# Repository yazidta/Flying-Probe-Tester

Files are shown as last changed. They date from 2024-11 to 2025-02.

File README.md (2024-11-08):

Flying Probe Tester for Single-Layer PCBs

This project is a Flying Probe Tester designed to perform connectivity testing on single-layer PCBs. 
The system uses two probes to make precise measurements across various points on the PCB,
identifying short circuits, open circuits, and verifying component placements and connections.

Key Features
Two-Probe System: Includes two probes for flexible testing of connections on single-layer PCBs.
Single-Layer PCB Support: Optimized for single-layer boards, providing efficient testing of simpler PCBs.
Automated Testing Sequences: Capable of performing automated testing sequences, saving time and improving accuracy.
Easy Setup and Calibration: Straightforward configuration for fast setup and reliable testing.
How It Works
The flying probe tester positions the probes over test points on the PCB and applies electrical signals to verify connections. 
This approach allows for rapid identification of faults without the need for dedicated test fixtures, making it suitable for both prototyping and small production runs.

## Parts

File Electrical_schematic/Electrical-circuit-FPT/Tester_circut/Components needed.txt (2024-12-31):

- 1x Buzzer with generator: (https://botland.com.pl/buzzery-generatory-dzwieku/786-buzzer-z-generatorem-5v-12mm-tht-5904422366940.html)
- 2x Resistor 100 ohm
- 1x Transistor BC547: (https://botland.com.pl/tranzystory-npn/254-tranzystor-bipolarny-npn-bc547b-50v-01a-5szt-5904422308025.html)

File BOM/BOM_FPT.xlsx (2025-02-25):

Component | Quantity | Price | Price x Quantity
Ball bearing 608 2RS 8x22x7mm 1 Set(10pcs) | 2 | PLN 9.50 | PLN 19.00
Round rod 56 cm x 12 mm 2 pcs. | 5 | PLN 23.95 | PLN 119.75
Linear Bearing | 8 | PLN 5.95 | PLN 47.60
Servo SG90 | 2 | PLN 12.70 | PLN 25.40
Toothed belt GT2 6mm 2m black | 2 | PLN 13.20 | PLN 26.40
FLEXIBLE ALUMINUM CLUTCH 5x8mm | 2 | PLN 6.39 | PLN 12.78
Bigtreetech TMC2209 v1.3 Stepper Motor Driver | 4 | PLN 27.90 | PLN 111.60
Mini limit switch sensor - WK601 - 5 pcs. | 1 | PLN 3.19 | PLN 3.19
Stepper motor JK42HS40-0504 200 steps/rev 12V/0.5A/0.43Nm | 2 | PLN 69.00 | PLN 138.00
140 jumper wires for breadboards | 1 | PLN 9.90 | PLN 9.90
Roll 625ZZ V-slot Ender 3 3D Printer 4 pcs | 2 | PLN 18.99 | PLN 37.98
Encoder with button | 1 | PLN 13.90 | PLN 13.90
4x20 LCD screen | 1 | PLN 34.90 | PLN 34.90
micro SD card | 1 | PLN 15.93 | PLN 15.93
Micro SD card reader | 1 | PLN 4.60 | PLN 4.60
NPN Transistors | 1 | PLN 1.90 | PLN 1.90
100 Ohm resistors | 1 | PLN 1.90 | PLN 1.90
Female - male cables | 2 | PLN 6.50 | PLN 13.00
Male to Male cables | 2 | PLN 6.50 | PLN 13.00
Female - female cables | 1 | PLN 6.50 | PLN 6.50
Buttons | 1 | PLN 3.90 | PLN 3.90
Power supply | 1 | PLN 44.90 | PLN 44.90
STM board | 1 | PLN 139.00 | PLN 139.00
Breadboard | 1 | PLN 7.70 | PLN 7.70
Capacitor 1uF 10pcs | 1 | PLN 1.50 | PLN 1.50
Converter | 3 | PLN 9.90 | PLN 29.70
Printed board | 1 | PLN 7.50 | PLN 7.50
On-Off switch | 1 | PLN 2.90 | PLN 2.90
Stepper motor LDO-42STH25-1404MAC | 2 | PLN 65.01 | PLN 130.02
Trapezoidal screws | 2 | PLN 26.99 | PLN 53.98
 |  | Total | PLN 1078.33

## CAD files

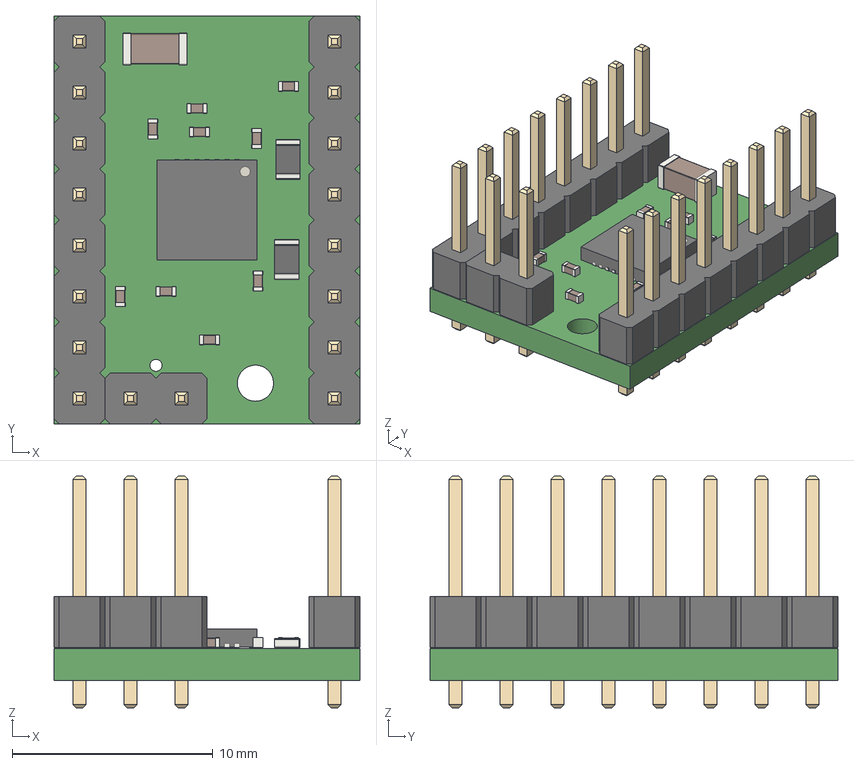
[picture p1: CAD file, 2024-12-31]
Electrical_schematic/Electrical-circuit-FPT/SilentStepStickKiCad-master/SilentStepStickKiCad-master/SilentStepStick-TMC2209_v20.step
15.2 x 20.3 x 11.5 mm

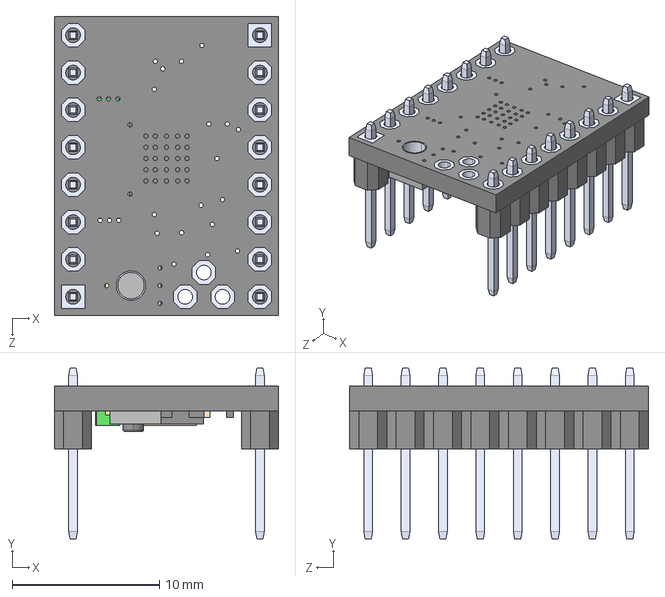
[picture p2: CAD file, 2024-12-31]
Electrical_schematic/Electrical-circuit-FPT/TMC2209_SILENTSTEPSTICK/TMC2209_SILENTSTEPSTICK.step
15.2 x 11.6 x 20.3 mm

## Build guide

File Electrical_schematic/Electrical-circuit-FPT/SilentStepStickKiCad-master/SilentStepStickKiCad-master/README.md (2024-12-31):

# SilentStepStickKiCad
SilentStepStick TMC2209 imported to KiCad

Imported https://github.com/watterott/SilentStepStick into KiCad.
Added 3D Models from KiCads Library.

Attribution goes to https://github.com/watterott.

Open-Source and released under the Creative Commons Attribution Share-Alike License.
https://creativecommons.org/licenses/by-sa/4.0/

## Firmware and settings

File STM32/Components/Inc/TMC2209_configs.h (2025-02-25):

/******************************************************************************
 * @file       TMC2209.cpp
 * @author     Ahmed Bouras
 * @date       05/12/2024
 * @version    0.6
 *
 * @copyright  Copyright (c) [2024] Ahmed Bouras
 *
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
 * @note       This library provides an interface for controlling the TMC2209
 *             stepper motor driver over STEP, DIR, ENN & UART.
 ******************************************************************************
 */
#ifndef TMC2209_CONFIGS_H
#define TMC2209_CONFIGS_H

#include "stm32f7xx_hal.h"
#include "stdbool.h"



// Timer Handler declaration for motors
extern TIM_HandleTypeDef htim1;
extern TIM_HandleTypeDef htim2;
extern TIM_HandleTypeDef htim3;
extern TIM_HandleTypeDef htim5;

// Motors & axis
#define MAX_MOTORS 4 // Max motors to be added -- You can handle upto 4 TMC2209 drivers on the same UART BUS
#define MAX_MOTORS_PER_AXIS 2 // Num of motors per axis
#define X_AXIS_LENGTH	469.356
#define Y_AXIS_LENGTH 	300


// DEFAULT DRIVERS CONFIGURATIONS

#define DEFAULT_MSTEP		16
#define DEFAULT_CHOPPERMODE	0
#define DEFAULT_SENDDELAY 	16
#define DEFAULT_IRUN 		12
#define DEFAULT_IHOLD 		6
#define DEFAULT_IDELAY		4
#define DEFAULT_COOLTHRS	5000
#define DEFAULT_SGTHRS		126
// DEFAULT MOTOR SPEED

#define DEFAULT_X_SPEED	8000
#define DEFAULT_Y_SPEED	8000







// Driver structure
typedef struct {
	uint8_t id;                      // Motor ID to identify each motor -- this is useless now ince we have address for uart
					//	Microstepping setting of the driver
    UART_HandleTypeDef *huart;
    uint8_t address;                // UART address
    uint32_t STATUS;
    TIM_HandleTypeDef *htim;        // Timer handle for PWM generation
    uint32_t step_channel;          // PWM channel
    uint32_t stepFrequency; 		// speed

    // Motor Configurations
    uint16_t mstep;	     // Microstepping: 2,8,16,256, or FULLSTEP
    uint8_t chopperMode; // 1 for StealthChop, 0 for SpreadCycle. Default: 1
    uint8_t sendDelay;
    uint32_t IFCNT; // Sucessful write incrementing counter(This value gets incremented with every sucessful UART write access 0 to 255 then wraps around.)
    uint8_t pdn_disable; // PDN_DISABLE FOR UART
    uint8_t GCONF;
    uint8_t IRUN;
    uint8_t IHOLD;
    uint8_t IDELAY;
    uint8_t stallEnabled; // STALL enabled flag, this means that we will be able to read sg_result
    uint32_t SG_RESULT;
    uint8_t checkSG_RESULT; // flag to check sg_result
    int32_t TCoolThrs;  // TCoolThrs for Stall detection on DIAG pin(we will have to set the step frequency which stall will be triggered)
    uint8_t standstill; // this indict that the motor is in standstill from DRV_STATUS


    // GPIO PINS
    GPIO_TypeDef *step_port;
    uint16_t step_pin;
    GPIO_TypeDef *dir_port;
    uint16_t dir_pin;
    GPIO_TypeDef *enn_port;
    uint16_t enn_pin;
    GPIO_TypeDef *diag_port;
    uint16_t diag_pin;
    GPIO_TypeDef *index_port;
    uint16_t index_pin;




} TMC2209_Driver;

// Motor tracking

typedef struct {
    TMC2209_Driver driver;         // Driver settings for the motor
    uint32_t stepsPerRevolution;	// Steps per revolution of the motor
    uint32_t totalStepsPerRevolution; // we will calculate this later based on the mstep option the driver has
    uint8_t moveRequest; 		// Move request Flag -- USED FOR RTOS
    int32_t stepsTaken;           // Count of steps taken
    int32_t fullSteps;
    uint32_t nextTotalSteps;           // Total steps the motor should take
    uint32_t direction;				// Direction of the Motor
    float prevPositionMM;	// Previous position on the axis in millimeter to no start the motor if it's in already in the requested position.
    float currentPositionMM; // Current position on the axis in millimeters
    float nextPositionMM;
    double stepError;
    bool isStepping;               // State to track if the motor is currently stepping
    uint32_t StepsFront;           // Tracking Steps Based on direction
    int32_t StepsBack;
    float calib[2];
    uint8_t STALL;
} Motor;

// Axis structure
typedef struct {
    Motor *motors[MAX_MOTORS_PER_AXIS];           // Pointing to which motors controlling this axis
    float lengthMM;         // Total length of the axis in millimeters
    uint32_t totalSteps;    // Total steps the motor takes to cover the axis length -- You can get this value using limit switches
    float stepPerUnit;      // How much one step would move on the axis
    char id[MAX_MOTORS_PER_AXIS][10];          //  Axis name with Motor ID (e.g., "X1", Y1", "Z1") "1" stands for the motor ID which control the axis
} Axis;




extern Motor motors[MAX_MOTORS]; // Global motor array
extern Axis axes[MAX_MOTORS_PER_AXIS];


// Function declarations
void initializeMotors();
void initializeAxis(Axis *axis, Motor *motor1, Motor *motor2, uint8_t circumference, const char *axisName);
void initializeSystem();
void TMC2209_setMotorsConfiguration(Motor *motors);



#endif // TMC2209_CONFIGS_H

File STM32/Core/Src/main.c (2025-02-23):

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
/* Includes ------------------------------------------------------------------*/
#include "main.h"
#include "cmsis_os.h"
#include "fatfs.h"

/* USER CODE BEGIN Includes */

#include "lcd_config.h"
#include "encoder.h"
#include "encoder_config.h"
#include "stm32f7xx_hal.h"
#include "TMC2209.h"
#include "TMC2209_configs.h"
#include "servo.h"
#include "fatfs.h"
#include "calibration.h"
#include "app_tasks.h"

/* USER CODE END Includes */


I2C_HandleTypeDef hi2c1;

SPI_HandleTypeDef hspi2;

TIM_HandleTypeDef htim1;
TIM_HandleTypeDef htim2;
TIM_HandleTypeDef htim3;
TIM_HandleTypeDef htim4;
TIM_HandleTypeDef htim5;
TIM_HandleTypeDef htim7;
TIM_HandleTypeDef htim9;
TIM_HandleTypeDef htim14;

UART_HandleTypeDef huart4;
UART_HandleTypeDef huart5;
UART_HandleTypeDef huart2;
UART_HandleTypeDef huart3;
UART_HandleTypeDef huart6;
DMA_HandleTypeDef hdma_uart4_rx;
DMA_HandleTypeDef hdma_uart5_rx;
DMA_HandleTypeDef hdma_usart2_rx;
DMA_HandleTypeDef hdma_usart3_rx;
DMA_HandleTypeDef hdma_usart3_tx;
DMA_HandleTypeDef hdma_usart6_rx;

PCD_HandleTypeDef hpcd_USB_OTG_FS;

osThreadId defaultTaskHandle;
/* USER CODE BEGIN PV */


SERVO_Handle_TypeDef hservo1 = { .PwmOut = PWM_INIT_HANDLE(&htim14, TIM_CHANNEL_1), .ID= 1 };
SERVO_Handle_TypeDef hservo2 = { .PwmOut = PWM_INIT_HANDLE(&htim9, TIM_CHANNEL_1), .ID=2 };

Motor motors[MAX_MOTORS]; // Global motor array
Axis axes[MAX_MOTORS_PER_AXIS]; // Global axes array

volatile uint8_t flagUserBtn = 0;

// ENDTOP FLAGS:
volatile uint8_t ES1 = 0;
volatile uint8_t ES2 = 0;
volatile uint8_t ES3 = 0;
volatile uint8_t ES4 =0;

volatile uint8_t Btn1 = 0;
volatile uint8_t Btn2 = 0;
volatile uint8_t Btn3 = 0;
volatile uint8_t Btn4 =0;
volatile uint8_t Btn5 =0;

// Homing Flags

volatile uint8_t homingFlag = 0;
volatile uint8_t calibrationFlag =0;


void SystemClock_Config(void);
static void MX_GPIO_Init(void);
static void MX_DMA_Init(void);
static void MX_USART3_UART_Init(void);
static void MX_USB_OTG_FS_PCD_Init(void);
static void MX_TIM7_Init(void);
static void MX_TIM4_Init(void);
static void MX_TIM2_Init(void);
static void MX_USART2_UART_Init(void);
static void MX_SPI2_Init(void);
static void MX_TIM3_Init(void);
static void MX_TIM14_Init(void);
static void MX_TIM5_Init(void);
static void MX_TIM9_Init(void);
static void MX_I2C1_Init(void);
static void MX_USART6_UART_Init(void);
static void MX_UART4_Init(void);
static void MX_UART5_Init(void);
static void MX_TIM1_Init(void);
void StartDefaultTask(void const * argument);

/* USER CODE BEGIN 0 */

void HAL_GPIO_EXTI_Callback(uint16_t GPIO_Pin)
{
    if (GPIO_Pin == USER_Btn_Pin) // Check if the interrupt is for the correct button
    {

    flagUserBtn = 1;
    }

}
/* USER CODE END 0 */

/**
  * @brief  The application entry point.
  * @retval int
  */
int main(void)
{

  /* MCU Configuration--------------------------------------------------------*/

  /* Reset of all peripherals, Initializes the Flash interface and the Systick. */
  HAL_Init();

  /* Configure the system clock */
  SystemClock_Config();

  /* Initialize all configured peripherals */
  MX_GPIO_Init();
  MX_DMA_Init();
  MX_USART3_UART_Init();
  MX_USB_OTG_FS_PCD_Init();
  MX_TIM7_Init();
  MX_TIM4_Init();
  MX_TIM2_Init();
  MX_USART2_UART_Init();
  MX_FATFS_Init();
  MX_SPI2_Init();
  MX_TIM3_Init();
  MX_TIM14_Init();
  MX_TIM5_Init();
  MX_TIM9_Init();
  MX_I2C1_Init();
  MX_USART6_UART_Init();
  MX_UART4_Init();
  MX_UART5_Init();
  MX_TIM1_Init();
  /* USER CODE BEGIN 2 */

  LCD_I2C_Init(&hlcd3);
 // LCD_I2C_Clear(&hlcd3);

  SERVO_Init(&hservo1);
  SERVO_Init(&hservo2);

  ENC_Init(&henc1);


  //initializeSystem();




 // TMC2209_SetSpeed(&motors[0], 7000);
 // TMC2209_Start(&motors[0]);


  /* USER CODE END 2 */

  /* USER CODE BEGIN RTOS_MUTEX */
  /* add mutexes, ... */

  testingEvent = xEventGroupCreate();
  configASSERT(testingEvent != NULL);
  calibEventGroup = xEventGroupCreate();
  configASSERT(calibEventGroup != NULL);

  lcdMutex = xSemaphoreCreateMutex();
  /* USER CODE END RTOS_MUTEX */

  /* USER CODE BEGIN RTOS_SEMAPHORES */
  /* add semaphores, ... */
  xInitSemaphore = xSemaphoreCreateMutex();

  /* USER CODE END RTOS_SEMAPHORES */

  /* USER CODE BEGIN RTOS_TIMERS */
  /* start timers, add new ones, ... */
  /* USER CODE END RTOS_TIMERS */

  /* USER CODE BEGIN RTOS_QUEUES */
  /* add queues, ... */
  /* USER CODE END RTOS_QUEUES */

  /* Create the thread(s) */
  /* definition and creation of defaultTask */
//  osThreadDef(defaultTask, StartDefaultTask, osPriorityNormal, 0, 512);
//  defaultTaskHandle = osThreadCreate(osThread(defaultTask), NULL);

  /* USER CODE BEGIN RTOS_THREADS */
  /* add threads, ... */

//  const osThreadAttr_t motorTask_attributes = {
//		  .name = "motorControlTask",
//		  .priority = (osPriority_t) osPriorityNormal,
//		  .stack_size = 512  // TODO: Adjust the stack size?
//  };
//  osThreadId_t motorTaskHandle = osThreadNew(motorControlTask, NULL, &motorTask_attributes);



  /* Create the main menu task */
  xTaskCreate(
	  motorControlTask,           /* Task function */
      "motorControlTask",          /* Task name (for debugging) */
      256,                     /* Stack size in words */
      NULL,         /* Task parameters */
	  tskIDLE_PRIORITY + 4,    /* Task priority */
      NULL                     /* Task handle (optional) */
  );

  xTaskCreate(
	  stallMonitorTask,          /* Task function */
      "StallMonitorTask",       /* Task name (for debugging) */
      128,        				/* Stack size in words */
      NULL,                     /* Task parameters */
	  tskIDLE_PRIORITY + 4,     /* Task priority */
      NULL                       /* Task handle (optional) */
  );

  xTaskCreate(
      vMainMenuTask,           /* Task function */
      "MainMenuTask",          /* Task name (for debugging) */
	  1024,                     /* Stack size in words */
      NULL,         /* Task parameters */
	  tskIDLE_PRIORITY + 1,    /* Task priority */
      NULL                     /* Task handle (optional) */
  );

  xTaskCreate(
	  vTestingTask,           /* Task function */
      "vTestingTask",          /* Task name (for debugging) */
	  768 ,                     /* Stack size in words */
      NULL,         /* Task parameters */
	  tskIDLE_PRIORITY + 3,    /* Task priority */
      NULL                     /* Task handle (optional) */
  );


  xTaskCreate(
      calibProcessTask,        /* Task function */
      "CalibProcessTask",      /* Task name */
      128,                     /* Stack size in words */
      NULL,                    /* Task parameters */
	  tskIDLE_PRIORITY + 2,    /* Task priority */
      NULL                     /* Task handle (optional) */
  );



  /* Start the FreeRTOS scheduler */
  vTaskStartScheduler();
  /* USER CODE END RTOS_THREADS */

  /* Start scheduler */
  osKernelStart();

  /* We should never get here as control is now taken by the scheduler */

  /* Infinite loop */
  /* USER CODE BEGIN WHILE */
   while (1){

      }

    /* USER CODE END WHILE */

}

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
/* USER CODE BEGIN Header_StartDefaultTask */
/**
  * @brief  Function implementing the defaultTask thread.
  * @param  argument: Not used
  * @retval None
  */
/* USER CODE END Header_StartDefaultTask */
void StartDefaultTask(void const * argument)
{
  /* USER CODE BEGIN 5 */
////  /* Infinite loop */
////  for(;;)
////  {
////   osDelay(1);
////  }
//
  /* USER CODE END 5 */
}

/**
  * @brief  Period elapsed callback in non blocking mode
  * @note   This function is called  when TIM6 interrupt took place, inside
  * HAL_TIM_IRQHandler(). It makes a direct call to HAL_IncTick() to increment
  * a global variable "uwTick" used as application time base.
  * @param  htim : TIM handle
  * @retval None
  */
void HAL_TIM_PeriodElapsedCallback(TIM_HandleTypeDef *htim)
{
  if (htim->Instance == TIM6) {
    HAL_IncTick();
  }
}

/**
  * @brief  This function is executed in case of error occurrence.
  * @retval None
  */
void Error_Handler(void)
{
  /* USER CODE BEGIN Error_Handler_Debug */
  /* User can add his own implementation to report the HAL error return state */
  __disable_irq();
  while (1)
  {
  }
  /* USER CODE END Error_Handler_Debug */
}

#ifdef  USE_FULL_ASSERT
/**
  * @brief  Reports the name of the source file and the source line number
  *         where the assert_param error has occurred.
  * @param  file: pointer to the source file name
  * @param  line: assert_param error line source number
  * @retval None
  */
void assert_failed(uint8_t *file, uint32_t line)
{
  /* USER CODE BEGIN 6 */
  /* User can add his own implementation to report the file name and line number,
     ex: printf("Wrong parameters value: file %s on line %d\r\n", file, line) */
  /* USER CODE END 6 */
}
#endif /* USE_FULL_ASSERT */

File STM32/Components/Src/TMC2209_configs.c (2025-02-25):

/******************************************************************************
 * @file       TMC2209.cpp
 * @author     Ahmed Bouras
 * @date       05/12/2024
 * @version    0.6
 *
 * @copyright  Copyright (c) [2024] Ahmed Bouras
 *
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
 * @note       This library provides an interface for controlling the TMC2209
 *             stepper motor driver over STEP, DIR, ENN & UART.
 ******************************************************************************
 */



#include "TMC2209.h"
#include "TMC2209_configs.h"
#include "app_tasks.h"

// UART declaration
// UART_HandleTypeDef huart2; in my case it's already generated in main.c


// Motors & axis
extern Motor motors[MAX_MOTORS];
extern Axis axes[MAX_MOTORS_PER_AXIS];


void initializeMotors() {
    // Initialize each motor in the array
    for (int i = 0; i < MAX_MOTORS; i++) {
    	// Setting all for all drivers/motors
    	 // UART handler
    	motors[i].driver.address = 0x02; // Address : 0x00, 0x01 ... Depends on MS1 AND MS2 // All drivers address 3 since they're on different uarts. If uart failed MSTEP 16 by default.

    	// Motor Parameters
    	motors[i].driver.id = i ;
    	motors[i].driver.STATUS = TMC_OK;
        motors[i].driver.GCONF = 0;
        motors[i].driver.IFCNT = 0;
        motors[i].driver.chopperMode = 0;
        motors[i].driver.SG_RESULT = 0;
        motors[i].driver.checkSG_RESULT = 0;
        motors[i].driver.TCoolThrs = 0;
        motors[i].driver.stepFrequency = 0;
        motors[i].driver.IRUN = 0;
        motors[i].driver.IHOLD = 0;


        motors[i].fullSteps = 0;
        motors[i].stepsTaken = 0;
        motors[i].nextTotalSteps = 0;
        motors[i].currentPositionMM = 0;
        motors[i].nextPositionMM = 0;
        motors[i].stepError = 0;
        motors[i].isStepping = false;
        motors[i].STALL = 0;



        if(i == 0){
         // Configure motor 1 X-axis

        // TIMER configurations
        motors[i].driver.huart = &huart2;
        motors[i].driver.htim = &htim2;				 // TIMER HANDLER
        motors[i].driver.step_channel = TIM_CHANNEL_3; // PWM channel for motor 1
        motors[i].driver.mstep = 0;

        motors[i].stepsPerRevolution = 200;
        // GPIO PINS
        motors[i].driver.step_port = STEP1_GPIO_Port;
        motors[i].driver.step_pin = STEP1_Pin;
        motors[i].driver.dir_port = DIR1_GPIO_Port;
        motors[i].driver.dir_pin = DIR1_Pin;
        motors[i].driver.enn_port = ENN1_GPIO_Port;
        motors[i].driver.enn_pin = ENN1_Pin;
        motors[i].driver.diag_port = DIAG1_GPIO_Port;
        motors[i].driver.diag_pin = DIAG1_Pin;


        }


        if(i == 1){
        	// Configure motor 2 X-axis
            // TIMER configurations
            motors[i].driver.htim = &htim1;				 // TIMER HANDLER
            motors[i].driver.step_channel = TIM_CHANNEL_4; // PWM channel for motor 1
            motors[i].driver.mstep = 0;
            motors[i].driver.huart = &huart4;
            motors[i].stepsPerRevolution = 200;
            // GPIO PINS
            motors[i].driver.step_port = STEP2_GPIO_Port;
            motors[i].driver.step_pin = STEP2_Pin;
            motors[i].driver.dir_port = DIR2_GPIO_Port;
            motors[i].driver.dir_pin = DIR2_Pin;
            motors[i].driver.enn_port = ENN2_GPIO_Port;
            motors[i].driver.enn_pin = ENN2_Pin;
            motors[i].driver.diag_port = DIAG2_GPIO_Port;
            motors[i].driver.diag_pin = DIAG2_Pin;


        }
        if(i == 2){
        	        	// Configure motor 3 Y-axis
        	            // TIMER configurations
            motors[i].driver.htim = &htim5;				 // TIMER HANDLER
        	motors[i].driver.step_channel = TIM_CHANNEL_1; // PWM channel for motor 1
            motors[i].driver.mstep = 0;
            motors[i].driver.huart = &huart5;
        	motors[i].stepsPerRevolution = 400;
        	            // GPIO PINS
            motors[i].driver.step_port = STEP3_GPIO_Port;
            motors[i].driver.step_pin = STEP3_Pin;
            motors[i].driver.dir_port = DIR3_GPIO_Port;
            motors[i].driver.dir_pin = DIR3_Pin;
            motors[i].driver.enn_port = ENN3_GPIO_Port;
            motors[i].driver.enn_pin = ENN3_Pin;
            motors[i].driver.diag_port = DIAG3_GPIO_Port;
            motors[i].driver.diag_pin = DIAG3_Pin;


        }
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

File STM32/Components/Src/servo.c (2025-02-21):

/*
 * servo.c
 *
 *  Created on: Nov 16, 2024
 *      Author: yazed
 */
#include "servo.h"




#define SERVO_MIN_DUTY 	2.5f
#define SERVO_MAX_DUTY 12.5f
extern SERVO_Handle_TypeDef hservo2;
extern SERVO_Handle_TypeDef hservo1;
/**
  * @brief Initialize PWM output
  * @param[in/out] hpwm   : PWM output handler
  * @retval None
  */

void PWM_Init(PWM_Handle_TypeDef* hpwm)
{
  PWM_WriteDuty(hpwm, hpwm->Duty);
  HAL_TIM_PWM_Start(hpwm->Timer, hpwm->Channel);
}

/**
  * @brief Write PWM duty cycle
  * @param[in/out] hpwm   : PWM output handler
  * @param[in]     duty   : PWM duty cycle in percents (0. - 100.)
  * @retval None
  */
void PWM_WriteDuty(PWM_Handle_TypeDef* hpwm, float duty)
{
  // Saturate duty cycle value
  if(duty < 0.0f)
    duty = 0.0;
  else if(duty > 100.0f)
    duty = 100.0f;
  // Write duty to handle field
  hpwm->Duty = duty;
  // Compute Capture/Compare Register value
  int COMPARE = (duty * (__HAL_TIM_GET_AUTORELOAD(hpwm->Timer)+1)) / 100;
  // Write value to register
  __HAL_TIM_SET_COMPARE(hpwm->Timer, hpwm->Channel, COMPARE);
}

/**
  * @brief Set PWM duty cycle
  * @param[in]     hpwm   : PWM output handler
  * @retval PWM duty cycle in percents (0. - 100.)
  */
float PWM_ReadDuty(const PWM_Handle_TypeDef* hpwm)
{
  return hpwm->Duty;
}
void SERVO_Init(SERVO_Handle_TypeDef* hservo)
{
	if(hservo->ID == 1 ){
	SERVO_WritePosition(hservo, SERVO1_HOME_POS); // Home position is 90 deg, Down is 72 deg.
	}
	else{
	SERVO_WritePosition(hservo, SERVO2_HOME_POS); // Home position is 50 deg, down is 40.
	}

	PWM_Init(&(hservo->PwmOut));
}

void SERVO_WritePosition(SERVO_Handle_TypeDef* hservo, float pos)
{
	hservo->Position = __SATURATION(pos, 0.0f, 180.0f);
	float duty = __LINEAR_TRANSFORM(hservo->Position, 0.0f, 180.0f, SERVO_MIN_DUTY, SERVO_MAX_DUTY);
	PWM_WriteDuty(&(hservo->PwmOut), duty);
}

float SERVO_ReadPosition(SERVO_Handle_TypeDef* hservo)
{
	return hservo->Position;
}

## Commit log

2024-11-16 Added some libraries
    Added the project file and some libraries for servo and endstop sensor
2024-11-30 Main menu
    Main menu working with encoder
    Startup animation
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2024-12-21 Added the SD_card_reader
    SD_card_reader configs + library
    Carriage Homing function
2024-12-21 Revert "Added the SD_card_reader"
    This reverts commit 2c0408e46764783b4d7935cc5c4ca096f2e51350.
    [Flying-Probe_tester.ioc, LCD.c, TMC2209.c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]
2024-12-22 Fixed the homing
    Fixed the homing
    deleted unnecessary things for optimization
    [Flying-Probe_tester.ioc, LCD.c, LCD.h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]
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2024-12-27 fixed the Moveto function
    Fixed the data types the current position is now updating
    Fixed the counting steps
    it is not counting infinitely now
    [TMC2209.c, TMC2209_configs.c, TMC2209_configs.h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]
2024-12-28 Fixed an LCD bug
    Fixed parts of row 3 and 4 printing in rows 1 and 2
    added the option to navigate and select files from the SD
    [LCD.c, LCD.h, main.c]
2024-12-28 Electronics folder add
    schematics
    [SilentStepStick-TMC2209_v20.kicad_pcb, SilentStepStick-TMC2209_v20.sch, SilentStepStick-TMC2209_v20.step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]
2024-12-31 configs,and calibration
    added pinouts and configs for the remaining componenets
    updated the calibration function
2024-12-31 MotorsPins
    Added the motors pins in the code
    Fixed the button debounce in the MotorButtonHandler function
    [Flying-Probe_tester.ioc, TMC2209.c, TMC2209_configs.c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]
2025-01-16 Add TMC2209_setSendDelay
    - AddedTMC2209_setSendDelay function for multi-node SENDDELAY configuration. SENDDELAY adds a delay (in multiples of eight bit times) before the driver responds to read requests, ensuring cleaner bus transitions when multiple TMC2209 drivers share a single UART line. This helps avoid collisions and UART framing error
    [TMC2209.c]
2025-01-16 Add TMC2209_setMotorsConfiguration
    - Added TMC2209_setMotorsConfiguration which configures all drivers according to their set microstepping and sendDelay value, enable spredCycle and enable PDNUART
2025-01-17 Add UART communication parser for PCB2Gcode Software
    -Developed a command parser to interpret and execute incoming UART commands from PCB2Gcode Software.
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2025-01-18 fixed Hardfault & LCD SD card menu
    [Flying-Probe_tester.ioc, LCD.c, LCD.h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]
2025-01-18 Modify and Fix TMC2209 communication
    - Made it so drivers (0, 1) for huart2 and (2, 3) for huart6 since the single-wire interface can handle not more than two drivers
    [Flying-Probe_tester.ioc, TMC2209.c, TMC2209.h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]
2025-01-19 Modify TMC2209 Driver UART communication
    - Made it so every driver has it's own UART interface
2025-01-20 Modify command_parser and debug buffers in TMC2209.c
    - Increased buffer sizes to avoid buffer overflows
    - Updated the command structure according to the updated PCB2Gcode commands.
    [TMC2209.c, TMC2209_configs.c, command_parser.c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]
2025-01-20 Electronics -> Electrical schematic transformation
    [SilentStepStick-TMC2209_v20.kicad_pcb, SilentStepStick-TMC2209_v20.sch, SilentStepStick-TMC2209_v20.step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]
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2025-01-21 Fix Sensors, TMC2209 UART Configurations
    Fix an issue where sensors(1,2) not being detected and Driver 0 UART not working properly
    [Flying-Probe_tester.ioc, TMC2209_configs.c, TMC2209_configs.h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]
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2025-01-22 Fixed Timer 1 configs for motor1 counting steps
    [Flying-Probe_tester.ioc, main.c]
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2025-01-22 Add calibration.c and calibration.h
    - Added new files for calibration logic
    - Moved calibration logic from TMC2209.c to calibration.c and calibration.h
2025-01-22 Update main.c and Modify MotorsHoming
    - Change MotorsHoming function type to bool.
    - Update main.c according to updated MotorsHoming function type
2025-01-23 Changed Homing and Calibration
    Added a function for Homing a motor
    and modified the HomingMotors function to call the MotorHoming for all motors
    Modified the calibration method
2025-01-23 Modify TMC2209 Driver Structure. Functions and Add error macros
    - Added IFCNT, IHOLD, IRUN, GCONF, chopperMode and STATUS variables to TMC2209 Driver structure.
    - Modified all UART functions to return variables to the modified TMC2209 Driver Structure.
    - Added ERROR macros for all UART functions
    [TMC2209.c, TMC2209.h, TMC2209_configs.c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]
2025-01-23 Schematic update
    [Fans.kicad_sch, Motor_drivers.kicad_sch, Tester_circut.kicad_pcb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]
2025-01-24 Add getStepPerUnit
    - Removed old stepsBack and stepsFront from PulseFinished Callback
    - Added a function which gets the step per unit of the motor passed to it.
2025-01-28 Update Command_parser.c and tmc2209.c
    - Updated command parser based on the previous update of TMC2209 structure update. We now check the configuration variable to verify if command is sent to TMC2209 successfully.
    - Fixed an issue with TMC2209_setMicrostepping where an if statement was blocking it at the start.
    [TMC2209.c, TMC2209.h, TMC2209_configs.c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]
2025-01-31 Add TMC2209_resetMotorsConfiguration function in tmc2209.c
    - Added macros for default configuration values
    - Added function to reset motor configuration which will be used in UART and program flow
    [TMC2209.c, TMC2209_configs.h]
2025-01-31 Add TMC2209_readTemperature function in tmc2209.c
    - Added a function which reads the DRVSTATUS temperature flags:
    - TMC2209 has 4 temperature flags:
    t120: >120°C (bit 10)
    t143: >143°C (bit 9)
    t150: >150°C (bit 8)
    t157: >157°C (bit7)
2025-01-31 Add TMC2209_enableStallDetection and TMC2209_checkStall in tmc2209.c
    - Added a function to enable the StallGuard feature in TMC2209 and adjust the threshold.
    - Added a variable stall and stallEnabled in the Driver structure .
    - Added a function that will read the stall flag and update the driver's stall variable.
    [TMC2209.c, TMC2209.h, TMC2209_configs.h]
2025-02-01 Fix stall detection function and Add fullsteps variable for motors
    - Fixed stall detection not detecting since SG_RESULT increments on every fullstep
    - Added new variable to count fullsteps for motors.
    [Flying-Probe_tester.ioc, TMC2209.c, TMC2209.h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]
2025-02-01 Update MotorHoming, and Motor_buttonHandler in Calibration.c
    -Made the homing for all motors start together
    -Fixed all directions based on the updated hardware setup
    -Added bool calibrationState to stop calibration when needed
    [calibration.c, main.c]
2025-02-02 Add readSGResult & Modfy checkStall in tmc2209.c and Modify .ioc file for DIAG Pins
    - Added a new function which check the stall and updates the variables accordingly.
    - Renamed old checkStall function to readSGResult
    - Added DIAG Pins for all drivers
    [Flying-Probe_tester.ioc, TMC2209.c, TMC2209.h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]
2025-02-02 Added Auto Calibration
    - The function calibrates the probes based a set physical reference point
2025-02-02 Add app_tasks.h and motorControlTask()
    - Created a command structure for motor commands to be used in motor control task
    - Added motorControlTask function which processes motor commands
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2025-02-02 Added back stepsFront and stepsBack in HAL_TIM_PWM_PulseFinishedCallback and fixes based on physical setup
    -Changed the motors in each axis based on the physical setup
    -Added back stepsFront and stepsBack to be able to calculate the position of each probe
    [TMC2209.c, TMC2209_configs.c]
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2025-02-03 Enhance LCD driver for RTOS and Add calibration, Menu and machine states and refactor RTOS tasks
    **LCD Driver Enhancements (LCD.c):
    - Improved the driver by adding new I2C functionalities to fit with RTOS
    - Implemented non-blocking delay functions to optimize timing operations and ensure smoother LCD interactions.
    - Enhanced utility functions for read buttons.
    ** RTOS Tasks Refactoring (app_tasks.c):
    - Introduced a different machine states with switch cases that will change.
    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
2025-02-04 schematic update
    probably final update
    [Motor_drivers.kicad_sch, Tester_circut.kicad_pcb, Tester_circut.kicad_sch]
2025-02-04 Added calibProcessTask
    - This task is supposed to Run the calibration protocol requested based on what the user picks from the vMainMenuTask
2025-02-04 Adjust tasks scheduling and task priority
    - Disabled default task and adjusted task priorities
    - Fix minor issues in LCD.cd
    [LCD.c, LCD.h, main.c]
2025-02-04 Fix vMainMenuTask, Modify lcd.c, and Change FREERTOS version
    -Modified Task Priorities
    -Modified MenuTemplate in lcd.c
    -Changed FreeRTOS version to CMSIS 1
    -Fixed vMainMenuTask Hardfaults
    [Flying-Probe_tester.ioc, LCD.c, LCD.h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]
2025-02-05 Add stallMonitorTask and Modify TMC2209_checkStall()
    - Added a task which checks a motor stalled and updates the motor's stall variable
    - Moved stall variable from drivers to motors structure
    - Renamed checkStallFlag to checkSG_RESULT
    [TMC2209.c, TMC2209_configs.c, TMC2209_configs.h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]
2025-02-05 Fix .ioc file and .project not generating correctly
    [Flying-Probe_tester.ioc, main.c]
2025-02-05 Modify UART Configuration in .ioc, Modify TMC2209_sendCommand and debug_print in tmc2209.c
    - Enabled DMA transmit for all uarts to operate in non-blocking mode to ensure other tasks will run without interference while uart is in the background.
    - Modified sendCommand and debug_print to the transmit in DMA mode
    [Flying-Probe_tester.ioc, TMC2209.c, main.c]
2025-02-05 Modify motorControlTask in app_tasks.c
    - Added motor configurations commands for speed, microstepping, chopper mode, stall guard threshold and cool threshold.
    [TMC2209.h, app_tasks.c, app_tasks.h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]
2025-02-05 Add MENU_STATE_WELCOME in app_tasks.c and Modify initializeSystem()
    - Modified the initializeSystem() to initialize motors, axis and motor configurations. After everything is initialized it sends a semaphore signal to menu welcome state
    - Added a menu state for welcome text and wait for semaphore signal from initializeSystem()
2025-02-05 Fixes for calibration functions
    -Fixed AutoCalibration motors not moving
    -Fixed not reading button inputs in semiAutoCalibration and ManulaCalibration
    [Flying-Probe_tester.ioc, LCD.c, LCD.h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]
2025-02-06 Modify processGcode in tmc2209.c, Modify app_tasks.c, and Modify sd_card_reader.c
    - Modified processGcode to fit with the FREERTOS and the update Gcode format of the PCB2Gcode software.
    - Moved processGcode to app_tasks.c aftrer modifications
    - Removed MenutaskParams since it's not being used.
    - Removed unnecessary functions from sd_card_Reader.c
2025-02-06 Fixes in LCD.c, Testing Task, Parsing Gcode
    - Made a task for testing the PCB
    - Fixed a bug in the SD card Menu
    - Added file Processing and parsing Gcode Logic
    [LCD.c, LCD.h, TMC2209_configs.c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]
2025-02-07 Added MoveAllMotors, testing, & fixes
    -Added MoveAllMotors that moves all the motors together
    -Added a function for moving the motors to the test points parsed from the file
    - Fixed the ProcessGcode function
    [TMC2209.c, TMC2209.h, TMC2209_configs.c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]
2025-02-08 Fix MoveAllMotorTo, adjust max priorities Modify Motor structure
    - Added if statement to check if motor is already in place to not move it
    - Increased max priorities from 7 to 12
    - moved ProcessGcode to MENU_STATE_SD
    [Flying-Probe_tester.ioc, TMC2209.c, TMC2209_configs.c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]
2025-02-08 Added generate_report fixed testingg and modified processGccode
    Added generate_report to generate a report of the test result
    Fixed testing logic in testingg function
    modified process Gcode to get information about nets
    [app_tasks.c, main.c]
2025-02-09 Modify tmc2209.c, tmc2209_configs.c and app_tasks.c
    - Fixed TMC2209 MSTEP not being changed on system reset
    - Modified TMC2209_enable_PDNUART() to TMC2209_setPDNUART() which now is able to enable or disable PDN UART of TMC2209 driver
    - Changed all drivers addresses to 3 since incase of a failed motor configuration, drivers will have default MSTEP of by MS1 and MS2(l16)
    -
    [Flying-Probe_tester.ioc, TMC2209.c, TMC2209.h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]
2025-02-09 Fixes in LCD.c, generate_report, calibration state machine, Encoder Period
    [Flying-Probe_tester.ioc, LCD.c, LCD.h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]
2025-02-09 Modify stallMonitorTask, calibProcessTas, preformTest(), Drivers SGTHRS and Add testingEventGroup
    - Modified SG threshold in tmc2209_config.c based on the load on stepper motors.
    - Modified stallMonitorTask:
    - Removed the old method of sending STOP commands to motor control as it will get queued leading to a delayed stopping of motors.
    - Called TMC2209_Stop() to stop the stall motor first then proceeding to stop the other motors.
    - Added a new event group 'testingEvent' to signal when there's a stall to abort testing, also, added a new bit for the exsisting 'calibEventGroup' to abort calibrating incase of a stall
    - Modified perfromTest() to receive 'TEST_STOP_BIT' in order to abort tes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
    [TMC2209_configs.c, app_tasks.c, app_tasks.h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]
2025-02-09 Revert "Merge branch 'main' of https://github.com/yazidta/Flying-Probe-Tester"
    This reverts commit 95dd93715bf08b3462259581eda44aa180f34e74, reversing
    changes made to b011b928c3800e4631f7aefb228693311c68d5b4.
    [Flying-Probe_tester.ioc, LCD.c, LCD.h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]
2025-02-21 Modify extras.c, servo.c and main.c to add new servo positions
    - Added macro for servo home and check positions.
    - Added new 'ID' variable in servo structure
    - Updated actual positions based on the physical setup
2025-02-22 Fixed Debouncing in ManualCalibration
    [Flying-Probe_tester.ioc, LCD.c, app_tasks.c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]
2025-02-22 ManualCalibration
    -Fixed not moving to the calibrated position& setting the current position
    [calibration.c]
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2025-02-22 Added a case for wrong files
    [app_tasks.c]
2025-02-22 Update calibProcessTask and vTestingTask in app_tasks.c
    - Add LCD screen for aborted calibration and test
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2025-02-23 Update preformTest() in app_tasks.c and Fix checkConnection()
    - Updated Probe GPIO pin to PULLDOWN since it's normally floating between 0-1
    - Fixed coordinates testResult not showing properly
    [app_tasks.c, main.c, servo.h]
2025-02-23 Fixed LCD screens, Fixed big files loading
    [LCD.c, LCD.h, app_tasks.c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]
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2025-02-24 Modify servo.h, tmc2209.c, tmc2209_configs.c
    - Tuned IHOLD, IRUN, IHOLDDELAY for motors
    - Updated servo angles
    - Updated AutoCalibration Points
2025-02-24 Revert "Modify servo.h, tmc2209.c, tmc2209_configs.c"
    This reverts commit 86f652067ec6db50a2a7aeb96442c78a3c8d7552.
    [TMC2209.c, TMC2209_configs.c, servo.h]
2025-02-24 Modify calibration.c, servo.h, tmc2209.c, tmc2209_configs.c
    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
2025-02-24 Modify tmc2209.c, tmc2209_configs.c
    - Fix wrong files from last commit
    [TMC2209.c, TMC2209_configs.c, TMC2209_configs.h]
2025-02-25 Schematics update
    +Electronics schematic
    +PCB design
    [Fans.kicad_sch, Motor_drivers.kicad_sch, Tester_circut.kicad_pcb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]
2025-02-25 Modify tmc2209_configs.c, tmc2209.c, and calibration.c
    - Added a new variable stepError to motor structure that will accumulate.
    - Update moveAllMotorsTo to round stepsMove and save the fractional error from rounding to motor->stepError.
    [TMC2209.c, TMC2209_configs.c, TMC2209_configs.h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]
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2025-02-25 Fixed File generation, MainMenu adjustments
    [LCD.c, app_tasks.c, extras.c]
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2025-02-25 BOM file upload
    [BOM_FPT.xlsx]

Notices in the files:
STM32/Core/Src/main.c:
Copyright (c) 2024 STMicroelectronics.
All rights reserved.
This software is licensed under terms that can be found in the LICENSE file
